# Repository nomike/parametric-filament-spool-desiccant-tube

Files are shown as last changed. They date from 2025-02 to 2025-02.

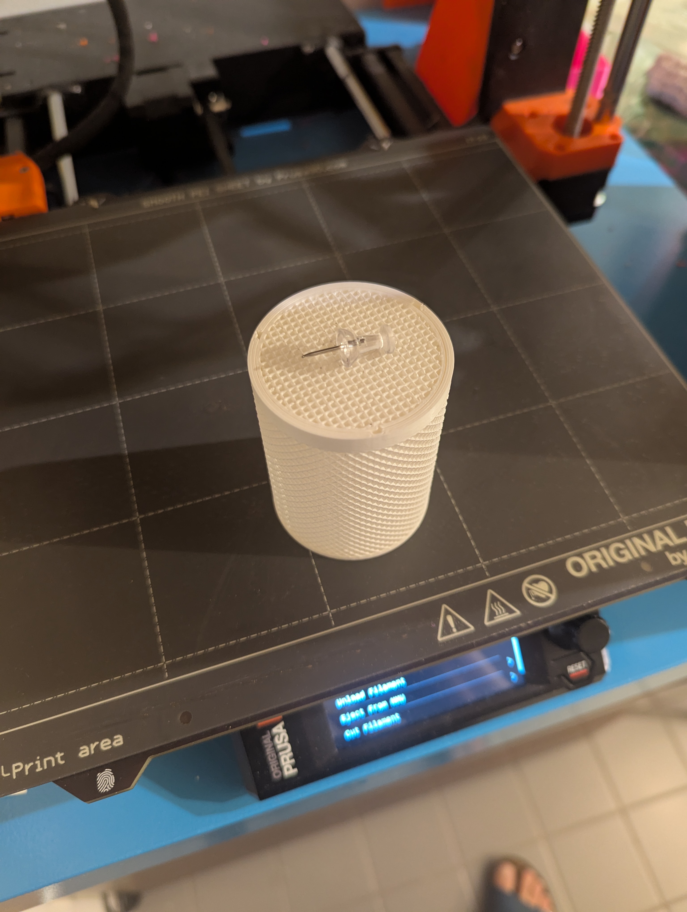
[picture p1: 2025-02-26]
photos/cork board pin for opening and closing the lid.jpg

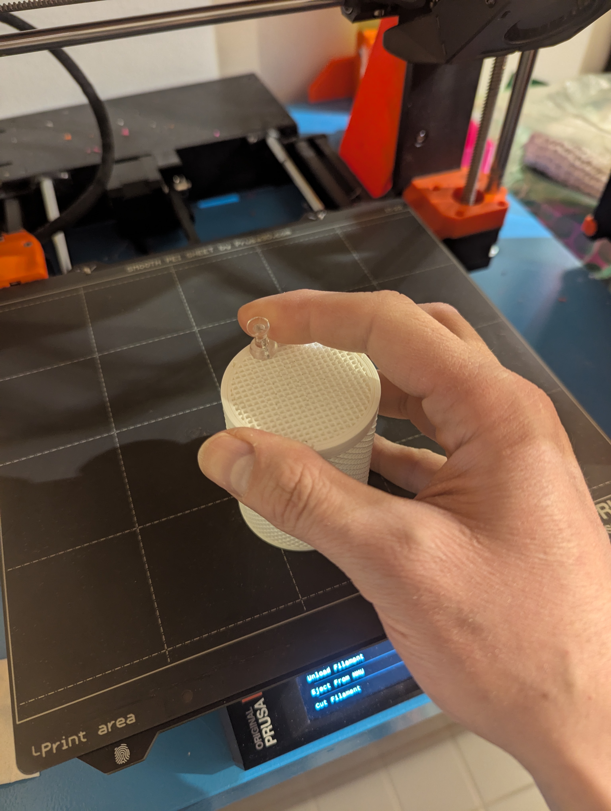
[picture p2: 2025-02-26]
photos/closing the lid.jpg

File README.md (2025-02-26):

Parametric filament spool desiccant container.

This container can be filled with loose desiccant pearls and placed in the center hole of a filament
spool, to keep it dry during storage.
It has a dense grid of square holes on all sides, which allows air to flow through the container and
reach the desiccant pearls.

The lid can be put on the container and secured by a short twist.

#### Models

As different filament spools have different center hole diameters and widths, there are multiple
models available.

I pre-rendered models for all the filament spool types I have at home right now. If you need any
other, you can generate them with OpenSCAD or the thibgiverse customizer.

| Spool Type | Spool |
|---|---|
| Type A | Extrudr 1 kg |
| Type B | Extrudr 0.75 kg  |
| Type C | Prusament 1 kg |
| Type D | Prusament 2 kg |
| Type E | Polymaker 1 kg |
| Type F | Flashforge 1 kg  |
| Type G | Filaflex 0.5 kg  |

#### Customizing

This design was made in OpenSCAD. The customizer feature on thingiverse is very limited though,
and can´t handle this design. To customize it, head over to GitHub (see link below) and clone the
entire repository (it uses git submodules, so you need to clone with `--recursive`).
You can then open the scad file in OpenSCAD and adjust the parameters to your needs using the
customizer Alternatively you can also manually set parameters in the parameter-json file and run
`make` to generate all STLs.

#### OpenSCAD rendering performance

The rendering performance in OpenSCAD is terrible. Rendering one type can easily take an hour or
more. However. newer versions of OpenSCAD have a new "manifold" backend, which cuts rendering time
down to a few seconds.

Unfortunately there hasn't been a release of OpenSCAD since 2021, so you have to get the source from
github and compile it yourself.

In OpenSCAD, go to "Edit" → "Preferences" → "Advanced" and set "3D Rendering" → "Backend" to "Manifold (new/fast)".

#### Thingiverse

<https://thingiverse.com/thing:6961859>

#### GitHub

<https://github.com/nomike/parametric-filament-spool-desiccant-container>

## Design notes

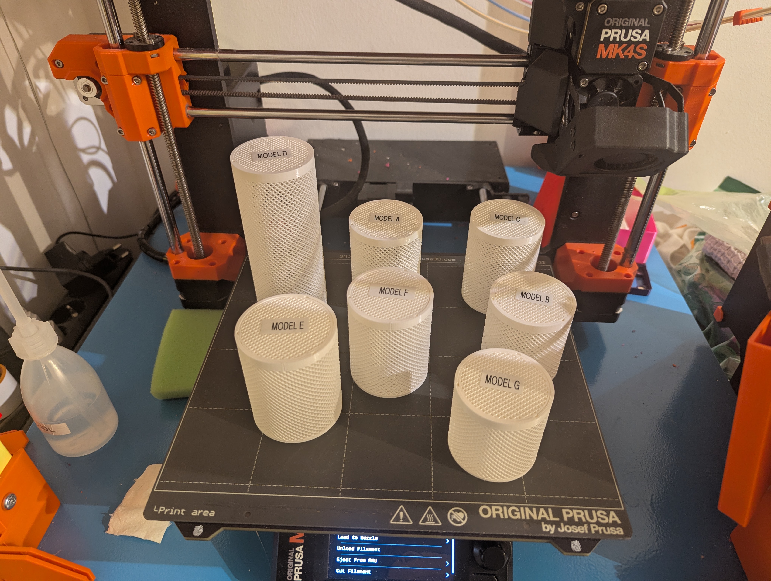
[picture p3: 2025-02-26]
photos/all models.jpg

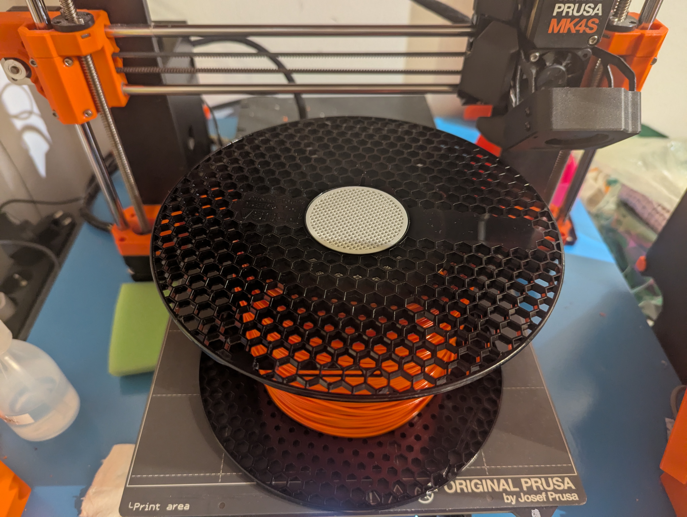
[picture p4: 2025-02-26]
photos/2kg prusament.jpg

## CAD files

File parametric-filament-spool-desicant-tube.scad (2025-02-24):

/**
Parametric filament spool desicant tube.

This tube can be filled with loose desicant pearls and placed in the center hole of a filament spool,
to keep it dry during storage.
It has a dense grid of square holes on all sides, which allows air to flow through the tube and reach the desicant pearls.

The lid can be put on the tube and secured by a short twist.
*/


/* [Tube dimmensions] */
/*
The tube is the main body of the design.
*/

// Overall diameter of the tube. Use calipers to measure your spool. Substract 0.2 mm as a safety
// margin.
tube_diameter = 52; // .1

// Length of the tube. This should be the same as the height of your spool.
tube_length = 67; // .1
// Thickness of the tube walls. 2 mm is a good value for a sturdy tube, 1 mm is too thin already.
wall_thickness = 2; //.1

/* [Air-flow grid dimmensions] */
/*
The air-flow grid is a dense grid of holes on all sides of the tube.
This allows air to flow through the tube and reach the desicant pearls.
The holes are designed to be squares, but they could be any regular polygon by tweaking the
grid_fn parameter. Values other than 4 are not tested yet and will reuire some code
changes to look good and be printable.
*/

// Size of a square hole in the air-flow grid. This is from corner to corner.
grid_size = 2.5;
//TODO: Calculation is wrong in the code below.
// Sacing between the holes in the air-flow grid.
grid_spacing = 0.5; // 0.1
// Margin between the grid and walls or corners.
grid_margin = 2;

// Number of sides of the grid-holes. Only 4 (squares) look good at the moment.
grid_fn = 4; // 1

// Spacing for the grid holes on the side-wall of the tube. This is the angle between the holes.
// The value of this parameter depends on the grid_size and the tube_diameter, so whenever you
// change those, you should recalibrate this parameter.
grid_angular_spacing = 7; //TODO: Calculate this automatically

/* [Lid dimmensions] */
/*
The lid is a separate piece that can be put on the tube and secured by a short twist.
If has two snaps on the side. These fit into guides on the tube and allows the lid to be secured
by a short twist.
*/

lid_thickness = 5; // .1
// Makes the lid slightly smaller so that it can fit inside the tube.
lid_tolerance = 0.2; // .1

// must be odd to ensure the snap has equal width through all axis.
lid_snap_fn = 7; // 1

/* [Snap Guides] */
/*
The snap guides are small ... on the inside of the tube. They guide the snaps of the lid and
allow it to be secured by a short twist.
Thers is a small nudge towards the end of the guide which holds the lid in place.
The nudge is designed a small cylinder.
*/

// Amount of degrees the lid needs to be twisted to be secured.
snap_guide_angle = 20;

// Diameter of the nudge cylinder.
snap_guide_nudge_diameter = 2;

// How much the nudge cylinder should stick out of the guide. Fine-tune this if the lid is too loose
// or too hard to snap into place.
snap_guide_nudge_width = 0.3;

/* [Features] */
// Whether to draw the tube or not.
draw_tube = true;
// Whether to draw the lid or not.
draw_lid = true;

// Rendering the whole design with small grid-holes is slow and makes the OpenSCAD editor laggy.
// This is temporarily enables to only render the first two lines of grid-holes on the tube,
// so that the rendering performance is improved and you can calibrate grid_angular_spacing.
// Set this to false once you're done with that calibration.
calibrate_grid_angular_spacing = false;


/* [Other parameters] */

// The lid is rendered above the tube to be able to be split into separate objects in the slicer.
// This parameter controls how much the lid is separated from the tube.
explode_width = 6;
// Number of fragments to use for the circles. Higher values make the circles look rounder but
// exponentially increase rendering time and filesize.
$fn = $preview ? 20 : 64;

// used to prevent z-fighting
EPSILON = 0.01;

/* [Calculated values] */
outer_circumference = tube_diameter * PI;
margin_top = lid_thickness + 1;
lid_snap_diameter = lid_thickness / 2;
snap_guide_rest_area_angle = lid_snap_diameter / outer_circumference * 360;

/*
    Module: circular_hole_grid

    Description:
        Creates a grid of square holes on a cylindrical surface. The holes are arranged in a
        staggered pattern.

    Parameters:
        - angular_spacing: The angular distance between holes in degrees.
        - diameter: The diameter of the cylindrical surface.
        - length: The length of the cylindrical surface.
        - hole_diameter: The diameter of each hole.
        - hole_fn: The number of facets used to approximate the circular holes.
        - grid_spacing: The distance between rows of holes.
        - calibrate_grid_angular_spacing: Boolean flag to adjust the grid angular spacing.

    Internal Variables:
        - true_angular_spacing: Adjusted angular spacing to ensure even distribution of holes.
        - z_step: The vertical distance between rows of holes.
        - grid_z: The number of rows of holes.

    Usage:
        This module can be used to create a pattern of holes on a cylindrical surface, which can be
        useful for designs requiring ventilation or weight reduction.
*/
module circular_hole_grid(angular_spacing, diameter, length, hole_diameter, hole_fn, grid_spacing, calibrate_grid_angular_spacing) {
  true_angular_spacing = 180 / (floor(180 / angular_spacing));
  z_step = (hole_diameter / 2) + (grid_spacing / sqrt(2));
  grid_z = ((calibrate_grid_angular_spacing) ? 2 : (length / z_step));

  for(z = [0:1:grid_z]) {
    angle_offset = (((z % 2) == 0) ? 0 : (true_angular_spacing / 2));
    for(angle = [0:true_angular_spacing:180]) {
      translate([0, 0, z * z_step])
        rotate([0, 90, angle + angle_offset])
          translate([0, 0, -(diameter + (2 * EPSILON)) / 2])
            cylinder(d = hole_diameter, h = diameter + (2 * EPSILON), $fn = hole_fn);
    }
  }
}

/*
    Module: rectangular_hole_grid

    Description:
        Creates a grid of square holes within a rectangular area. The holes are arranged in a
        staggered pattern.

    Parameters:
        x_size        - The width of the rectangular area.
        y_size        - The height of the rectangular area.
        height        - The height of the cylindrical holes.
        hole_diameter - The diameter of each cylindrical hole.
        hole_fn       - The number of facets used to approximate the cylindrical hole.
        hole_spacing  - The spacing between the edges of adjacent holes.

    Example Usage:
        rectangular_hole_grid(100, 50, 10, 5, 50, 10);
*/
module rectangular_hole_grid(x_size, y_size, height, hole_diameter, hole_fn, hole_spacing) {
  grid_x = x_size / (hole_spacing + hole_diameter);
  grid_y = y_size / (hole_spacing + hole_diameter);
  grid_x_dimmension = grid_x * (hole_spacing + hole_diameter);
  grid_y_dimmension = grid_y * (hole_spacing + hole_diameter);
  translate([(hole_diameter + hole_spacing) / 2, 0, 0])
    for(y = [0:1:grid_y * 2]) {
      x_offset = (((y % 2) == 0) ? 0 : (-(hole_spacing + hole_diameter) / 2));
      x_add = ((y % 2) == 0) ? 0 : 1;
      translate([x_offset, 0, 0])
        for(x = [0:1:grid_x + x_add]) {
          translate([x * (hole_spacing + hole_diameter), (y * (hole_spacing + hole_diameter)) / 2, 0])
            cylinder(d = hole_diameter, h = height, $fn = hole_fn);
        }
    }
}

/*
    Module: tube_bottom

    Description:
        Creates the bottom part of a tube with a grid pattern of holes.

    Parameters:
        - tube_diameter: Diameter of the tube.
        - height: Height of the tube.
        - grid_margin: Margin for the grid pattern.
        - grid_size: Diameter of the holes in the grid pattern.
        - grid_fn: Number of facets used to approximate the holes.
        - grid_spacing: Spacing between the holes in the grid pattern.

    Usage:
        tube_bottom(tube_diameter, height, grid_margin, grid_size, grid_fn, grid_spacing);

    Example:
        tube_bottom(50, 10, 2, 5, 16, 10);
*/
module tube_bottom(tube_diameter, height, grid_margin, grid_size, grid_fn, grid_spacing) {
  union() {
    difference() {
      cylinder(d = tube_diameter, h = height);
      translate([0, 0, -EPSILON])
        cylinder(d = tube_diameter - grid_margin, h = height + (2 * EPSILON));
    }
    difference() {
      cylinder(d = tube_diameter, h = height);
      translate([-tube_diameter / 2, -tube_diameter / 2, -EPSILON])
        rectangular_hole_grid(x_size = tube_diameter, y_size = tube_diameter, height = height + (2 * EPSILON), hole_diameter = grid_size, hole_fn = grid_fn, hole_spacing = grid_spacing);
    }
  }
}
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

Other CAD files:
parametric-filament-spool-desiccant-tube.scad

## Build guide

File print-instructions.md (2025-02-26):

No supports needed. Print container and lid as two separate objects.

Be aware, that the small grid cells require good bed adhesion. I had to clean my smooth PEI sheet
with dish-soap and water as IPA was not sufficient.

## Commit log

2025-02-23 Initial version.
    [parametric-filament-spool-desicant-tube.scad]
2025-02-23 Fix lip snap guides.
    [parametric-filament-spool-desicant-tube.scad]
2025-02-23 Explicitely pass all used variables as parameters to the various modules.
    [parametric-filament-spool-desicant-tube.scad]
2025-02-23 Make EPSILON uppercase to denote it's a global variable.
    [parametric-filament-spool-desicant-tube.scad]
2025-02-23 Use explicit brakets in mathematical calculations to be consitent and increase readability.
    [parametric-filament-spool-desicant-tube.scad]
2025-02-23 Document and group partameters. Remove unused ones.
    [parametric-filament-spool-desicant-tube.scad]
2025-02-23 Reformat function signatures.Explicitely pass parameters to method `lid_snap_guide`.
    [parametric-filament-spool-desicant-tube.scad]
2025-02-23 Improve formatting of method signatures.
    [parametric-filament-spool-desicant-tube.scad]
2025-02-23 Format code.
    [parametric-filament-spool-desicant-tube.scad]
2025-02-23 Add mostly AI generated doc-comments to the modules.
    [parametric-filament-spool-desicant-tube.scad]
2025-02-23 Add missing parameyters in call to `tube_bottom()`.
    [parametric-filament-spool-desicant-tube.scad]
2025-02-23 Fix tube_bottom height.
    [parametric-filament-spool-desicant-tube.scad]
2025-02-23 Set proper default grid_size.
    [parametric-filament-spool-desicant-tube.scad]
2025-02-23 Increase default angular resolution.
    [parametric-filament-spool-desicant-tube.scad]
2025-02-23 Turn off calibrate_grid_angular_spacing debug mode.
    [parametric-filament-spool-desicant-tube.scad]
2025-02-24 Set default circle fragments to a lower value on preview mode to improve responsiveness of OpenSCAD GUI.
    [parametric-filament-spool-desicant-tube.scad]
2025-02-24 Fix typo in tube_bottom creation.
    [parametric-filament-spool-desicant-tube.scad]
2025-02-24 Fix spelling of "desiccant".
    [parametric-filament-spool-desiccant-tube.scad]
2025-02-24 Add print instructions.
2025-02-24 Add parmaters for different filament brands.
2025-02-24 Rename variables for more clarity.
    [parametric-filament-spool-desiccant-tube.scad]
2025-02-24 Fix lid-snap size calculation.
    [parametric-filament-spool-desiccant-tube.scad]
2025-02-24 Increase lid tolerance as the fit was slightly too tight.
    [parametric-filament-spool-desiccant-tube.scad]
2025-02-24 Adjust snap guide nudge width for improved lid fit.
    [parametric-filament-spool-desiccant-tube.scad]
2025-02-24 Allow an arbitrary number of configurable snaps.
    [parametric-filament-spool-desiccant-tube.scad]
2025-02-26 Add note about bed adhesion to print instructions.
